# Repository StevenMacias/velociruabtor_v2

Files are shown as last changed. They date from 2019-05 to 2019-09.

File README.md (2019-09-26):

# VelocirUABtor v2

Competition line follower developed with the [UAB](https://www.uab.cat/web/universitat-autonoma-de-barcelona-1345467954774.html) Physical Computing Communitiy sponsorhip.

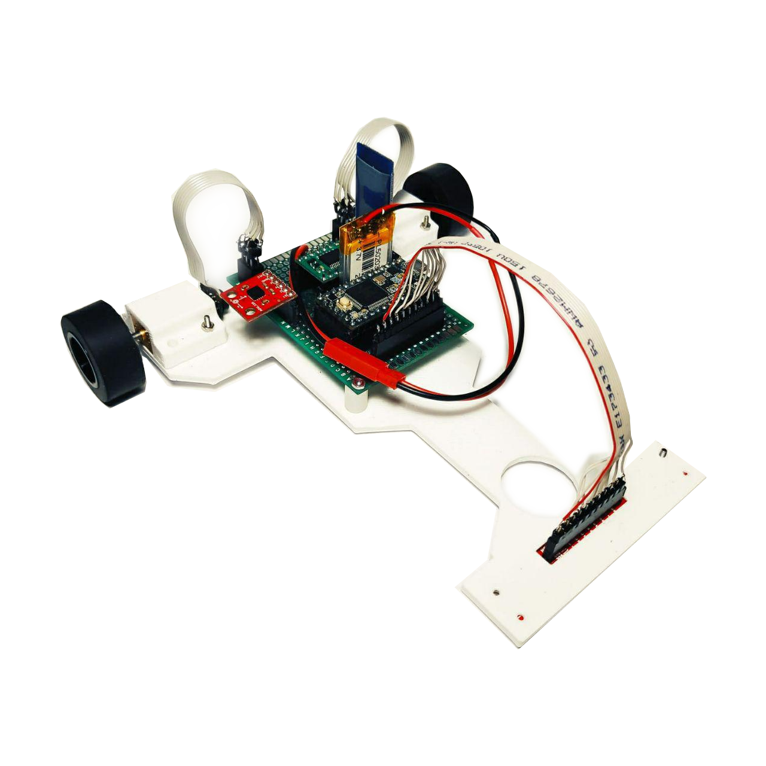
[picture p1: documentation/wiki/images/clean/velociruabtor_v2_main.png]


## Built With

In order to work in the project we recommend to use:
* [Atom](https://atom.io) - IDE.
* [PlatformIO](https://platformio.org/install/ide?install=atom) - Framework used to work with Teensy 3.2 that can be integrated in Atom.
* [GitKraken](https://www.gitkraken.com/) - Multiplatform Git client.
* [Procesing](https://processing.org/) - Language used to develop the user interface.
* [Fritzing](https://fritzing.org/home/) - Tool used to design the hardware connections.

## Main Components
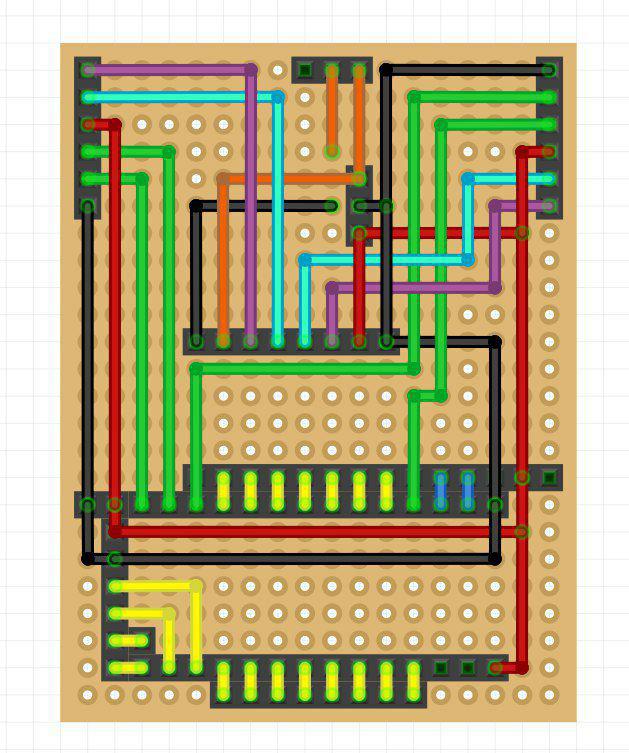
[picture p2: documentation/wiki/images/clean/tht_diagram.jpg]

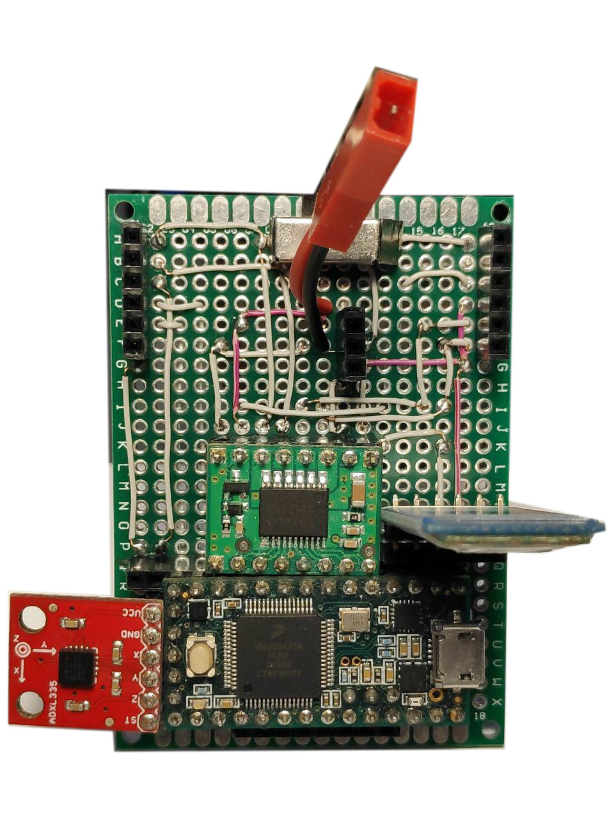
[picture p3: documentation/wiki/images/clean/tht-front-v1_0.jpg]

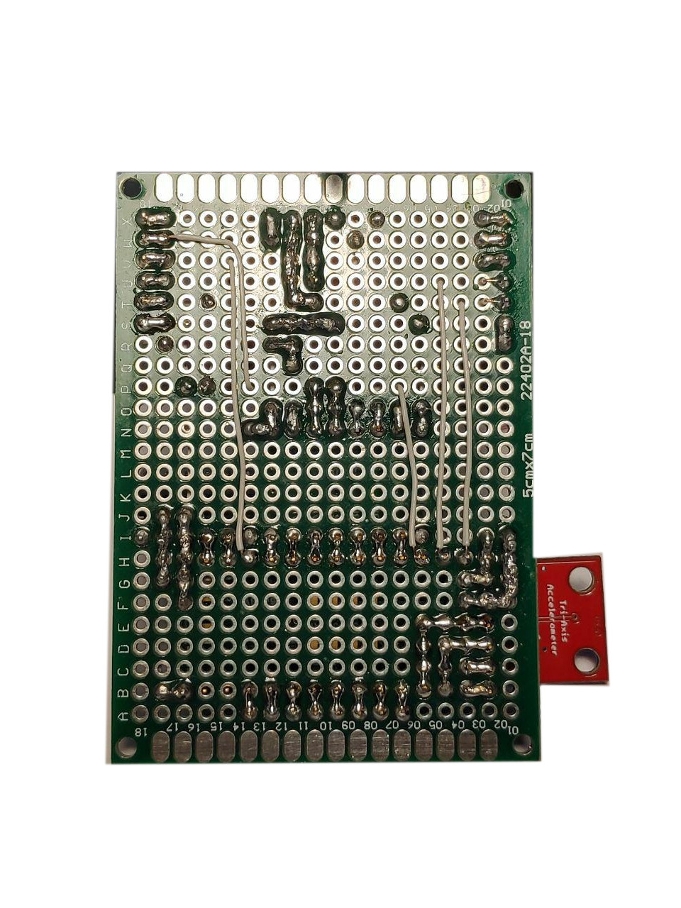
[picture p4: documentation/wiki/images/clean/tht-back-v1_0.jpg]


* [ADXL335](https://www.sparkfun.com/products/9269) - Accelerometer.
* [HC-05](https://components101.com/wireless/hc-05-bluetooth-module) - Bluetooth Module.
* [Pololu Magnetic Encoders](https://www.pololu.com/product/2598) - Encoders for micrometal motors.
* [TB6612FNG](https://www.pololu.com/product/713) - Motor Driver.
* [Reflectance Sensor Array](https://www.pololu.com/product/713) - Array of 8 IR sensors used to detect the track.
* [Teensy 3.2](https://www.pjrc.com/store/teensy32.html) -  32 bit ARM processor.

## User Interface
The microcontroller builds JSON frames with the sensors values that are transmitted to the laptop using the HC-05 module. 

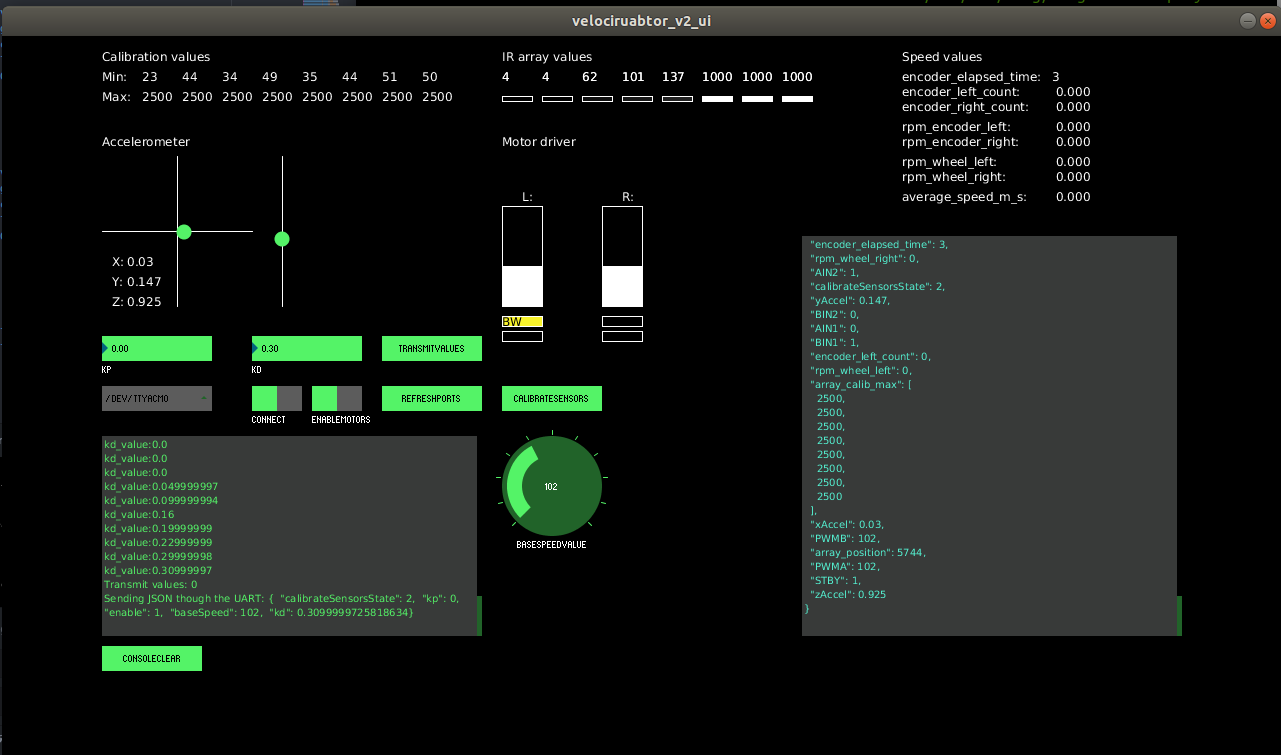
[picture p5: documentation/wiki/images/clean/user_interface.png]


## Authors

* **Steven Macías** - *Initial work* - [StevenMacias](https://github.com/StevenMacias)

## Contributors

* **Victor Escobedo** - *User interface features.* - [victorEscobedo](https://github.com/victorEscobedo)

## Acknowledgments

* **Fernando Vilariño** - *Mentor* - [Linkedin: fernandovilarino](https://www.linkedin.com/in/fernandovilarino/)

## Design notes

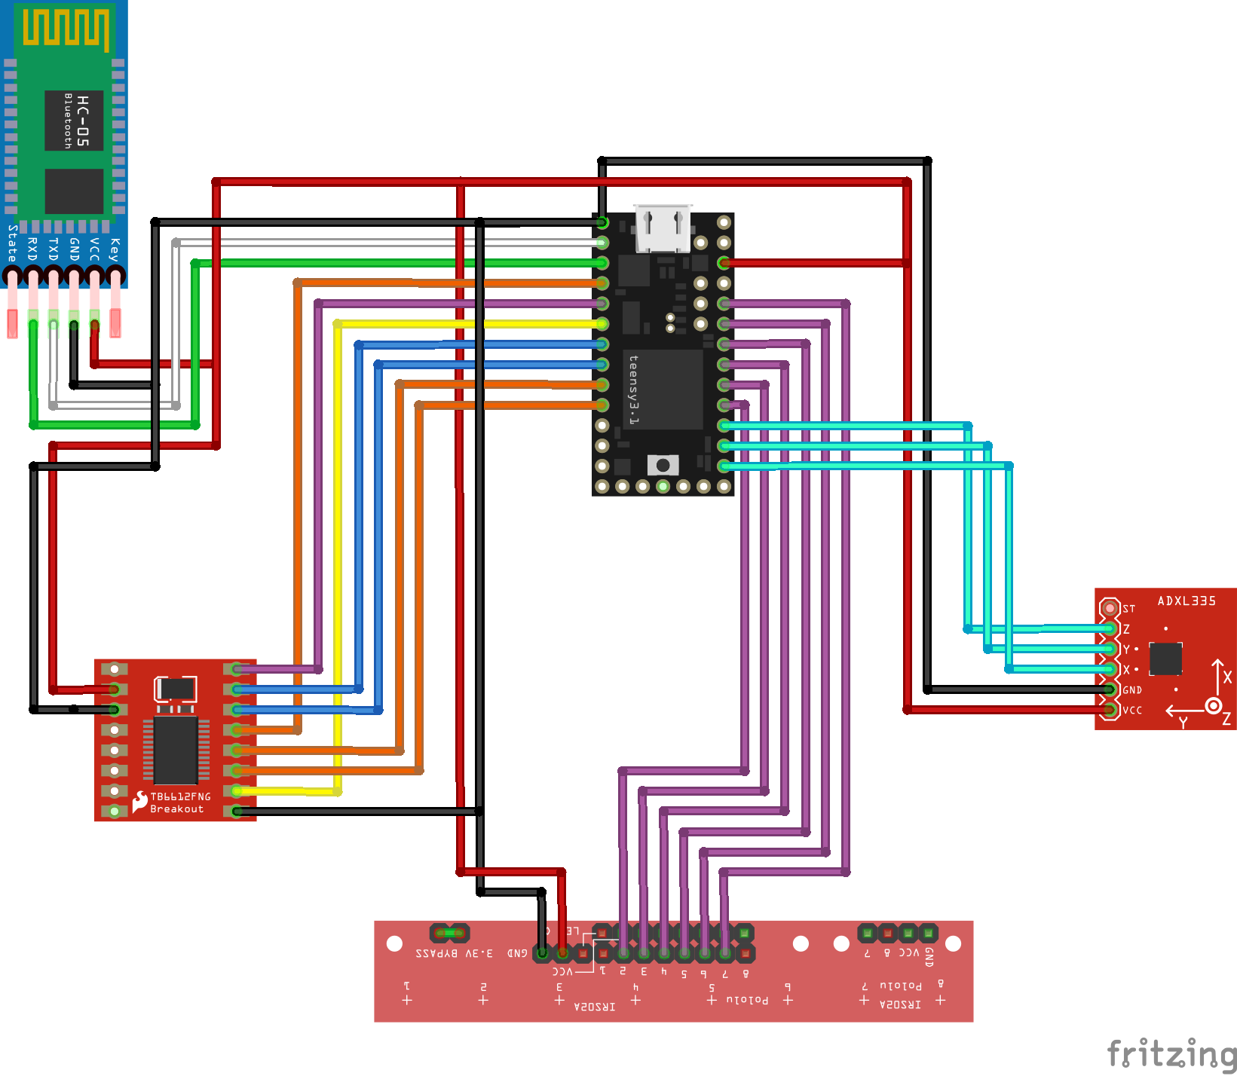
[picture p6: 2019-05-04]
documentation/System_Design/Fritzing/pictures/04_05_19/velociruabtor_v2_bb.png

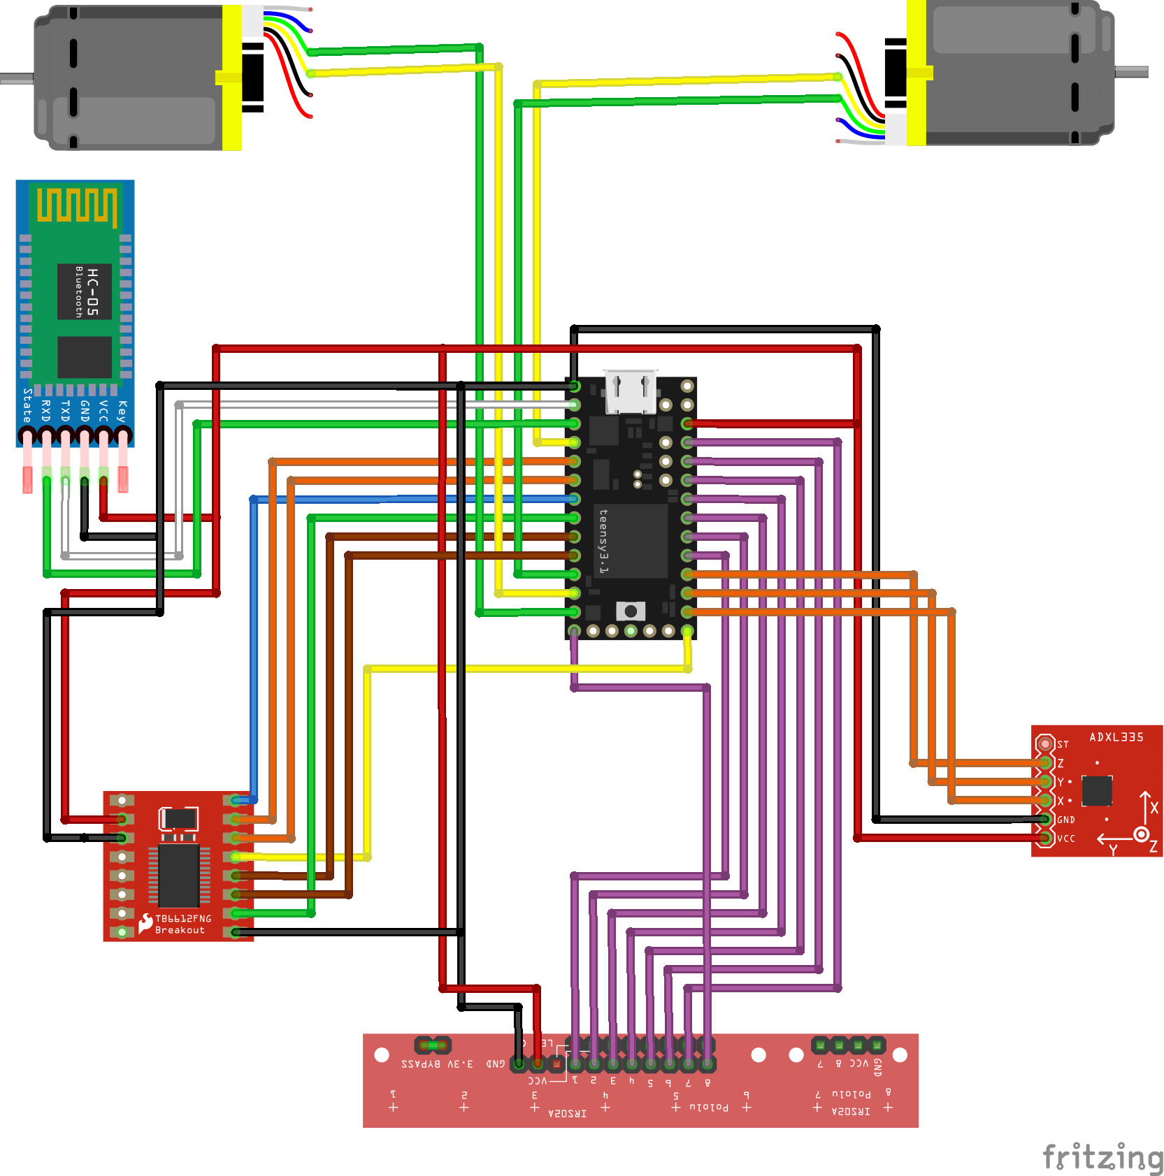
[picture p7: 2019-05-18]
documentation/System_Design/Fritzing/pictures/15_05_19/velociruabtor_v2_bb.png

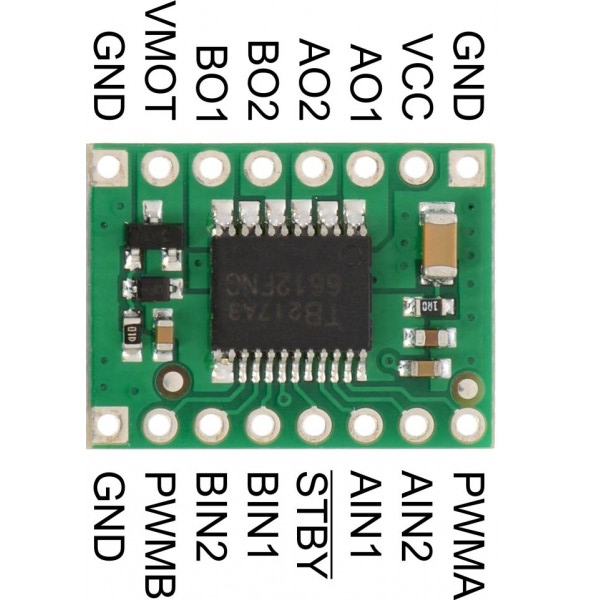
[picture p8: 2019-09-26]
documentation/System_Design/Hardware/Motor_Driver-TB6612FNG/tb6612fng_pinout.jpg

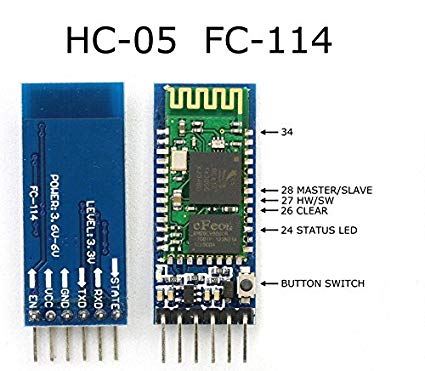
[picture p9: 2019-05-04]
documentation/System_Design/Hardware/Bluetooth-HC05/HC05-pinout.jpg

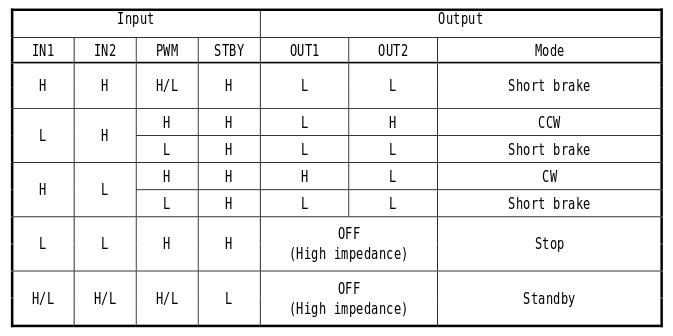
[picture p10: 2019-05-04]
documentation/System_Design/Hardware/Motor_Driver-TB6612FNG/motor_driver_table.png

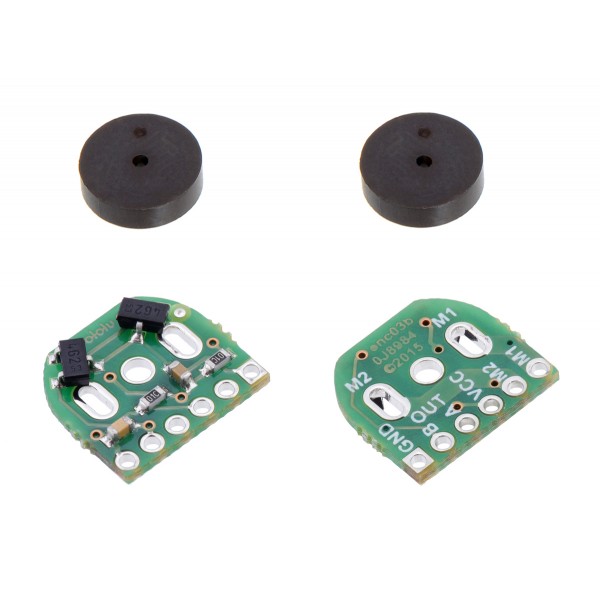
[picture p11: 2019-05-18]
documentation/System_Design/Hardware/Encoders/encoders-para-motores-micro-metal-12cpr.jpg

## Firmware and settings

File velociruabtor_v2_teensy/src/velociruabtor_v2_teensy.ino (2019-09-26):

/**
Velociruabtor V2
velociruabtor_v2_teensy.ino
Purpose: Develop a line follower using Teensy 3.2

@author Steven Macías and Victor Escobedo
@version 1.0 22/04/2019
*/
#include <Arduino.h>
#include <ArduinoJson.h>
#include <QTRSensors.h>
#include <Encoder.h>
#include "Accelerometer.h"
#include "Motor_driver.h"

#define PI 3.1415926535897932384626433832795
#define WHEEL_GEAR_DIVIDER 10.00
#define WHEEL_DIAMETER_MILIMETERS 28.00
#define WHEEL_PERIMETER (PI*WHEEL_DIAMETER_MILIMETERS)
#define ENCODER_OPTIMIZE_INTERRUPTS
#define BT_SERIAL Serial1
#define CABLE_SERIAL Serial
#define BT_UART_BAUDRATE 38400
#define CABLE_UART_BAUDRATE 115200
#define NUM_SENSORS 8
#define ARDUINOJSON_DEFAULT_NESTING_LIMIT 4

#define Kp 0.1 // experiment to determine this, start by something small that just makes your bot follow the line at a slow speed
#define Kd 4// experiment to determine this, slowly increase the speeds and adjust this value. ( Note: Kp < Kd)
#define MaxSpeed 255// max speed of the robot
#define BaseSpeed 255 // this is the speed at which the motors should spin when the robot is perfectly on the line
#define NUM_SENSORS  8     // number of sensors used
#define speedturn 180


QTRSensorsRC qtrrc((unsigned char[]) {A2, A3, A4, A5, A6, A7, A8, A9} ,NUM_SENSORS, 2500, QTR_NO_EMITTER_PIN);
StaticJsonDocument<1024> json;
StaticJsonDocument<2048> rx_json;
Accelerometer accel;
Motor_driver motor_driver;
int position = 0;
unsigned int sensorValues[NUM_SENSORS];
int motorValues[7];
int lastError = 0;
unsigned long start_time = millis();
unsigned long end_time = millis();
Encoder encoderLeft(2, 10);
Encoder encoderRight(12, 11); // Pins inversed
float rpm_encoder_left = 0;
float rpm_encoder_right = 0;
float rpm_wheel_left = 0;
float rpm_wheel_right = 0;
float average_speed_m_s = 0;
int calibrateSensorsState = 0;
int jsonError = 0;
unsigned long encoder_elapsed_time = 0;
long encoder_left_count, encoder_right_count;
char serial_data[2048] = "";
int enable = 0;
float kp = 1;
float kd = 1;
int baseSpeed = 0;
int maxSpeed = 255;
int period = 200;
unsigned long time_now = 0;
boolean lets_start = false;

const byte numChars = 512;
char receivedChars[numChars];   // an array to store the received data
boolean newData = false;


/**
Builds a JSON string that contains all the data regarging the line follower.
@param none
@return void
*/
void buildAccelJson()
{
  json.clear();
  // Acceleremoter values
  json["xAccel"] = accel.getX();
  json["yAccel"] = accel.getY();
  json["zAccel"] = accel.getZ();

  // Array Sensors values
  uint8_t i;
  for(i=0; i<NUM_SENSORS; i++)
  {
    json["array_calib_min"].add(qtrrc.calibratedMinimumOn[i]);
    json["array_calib_max"].add(qtrrc.calibratedMaximumOn[i]);
    position = qtrrc.readLine(sensorValues);
    json["array_values"].add(sensorValues[i]);
  }
  json["array_position"] = position;
}

/**
Builds a JSON string that contains all the data regarging the motor driver.
@param none
@return void
*/
void buildMotorDriverJson()
{
  json["PWMA"] = motorValues[0];
  json["AIN1"] = motorValues[2];
  json["AIN2"] = motorValues[1];
  json["PWMB"] = motorValues[3];
  json["BIN1"] = motorValues[4];
  json["BIN2"] = motorValues[5];
  json["STBY"] = motorValues[6];
}

void buildEncoderJson()
{
  json["rpm_encoder_left"] = rpm_encoder_left;
  json["rpm_encoder_right"] = rpm_encoder_right;
  json["encoder_elapsed_time"] = encoder_elapsed_time;
  json["rpm_wheel_left"] = rpm_wheel_left;
  json["rpm_wheel_right"] = rpm_wheel_right;
  json["average_speed_m_s"] = average_speed_m_s;
  json["encoder_left_count"] = encoder_left_count;
  json["encoder_right_count"] = encoder_right_count;
  json["calibrateSensorsState"] = calibrateSensorsState;
  json["jsonError"] = jsonError;
  json["lets_start"] = lets_start;
}


/**
Calibrates the QTR-RC Sensor array
@param none
@return void
*/
void calibrateQtrc()
{
  int i = 0;
  for (int i; i < 20; i++) // calibrate for sometime by sliding the sensors across the line, or you may use auto-calibration instead
  { 	//Added open brace here

    // GO TO RIGHT
    if ( i  <= 5 || i >= 15 ) // turn to the left and right to expose the sensors to the brightest and darkest readings that may be encountered
    {
      motor_driver.runMotorDriver(85, LOW, HIGH, 85, LOW, HIGH, HIGH);
    }
    // GOT TO LEFT
    else
    {
      motor_driver.runMotorDriver(85, HIGH, LOW, 85, HIGH, LOW, HIGH);
    }
    qtrrc.calibrate();
    delay(20);

  }  	//Added close brace here
  calibrateSensorsState = 2;
  motor_driver.runMotorDriver(0, LOW, HIGH, 0, HIGH, LOW, LOW);

}

/**
Function that initializes the system
@param none
@return void
*/
void setup()
{
  pinMode(LED_BUILTIN, OUTPUT);
  pinMode(A1, INPUT);
  pinMode(A0, INPUT);
  pinMode(A14, INPUT);
  //digitalWrite(LED_BUILTIN, HIGH);
  json.clear();
  // Configure Bluetooth UART
  BT_SERIAL.begin(BT_UART_BAUDRATE);
  // Configure USB UART
  CABLE_SERIAL.begin(CABLE_UART_BAUDRATE);
  // Create Objects
  accel = Accelerometer();
  motor_driver = Motor_driver();
  //motor_driver.enableMotors();
  // Calibrate Sensors Array
  calibrateQtrc();
  //digitalWrite(LED_BUILTIN, LOW);
  BT_SERIAL.setTimeout(200);
}

/**
Test function for the motor driver
@param none
@return void
*/
void testMotorDriver()
{
  static int i=0;
  static bool forward = true;

  if(forward == true)
  {
    motor_driver.runMotorDriver(i, LOW, HIGH, i, LOW, HIGH, HIGH);
  }else{
    motor_driver.runMotorDriver(i, HIGH, LOW, i, HIGH, LOW, HIGH);
  }
  i++;
  if(i>=255)
  {
    forward = !forward;
    i = 0;
  }
}

void computePidAndDrive()
{
  position = qtrrc.readLine(sensorValues); // get calibrated readings along with the line position, refer to the QTR Sensors Arduino Library for more details on line position.

  if(position>6700){
    //motor_driver.runMotorDriver(speedturn, HIGH, LOW, speedturn, LOW, HIGH, enable);
    motor_driver.runMotorDriver(baseSpeed, HIGH, LOW, baseSpeed, HIGH, LOW, enable);
    return;
  }
  if(position<300){
    //motor_driver.runMotorDriver(speedturn, LOW, HIGH, speedturn, HIGH, LOW, enable);
    motor_driver.runMotorDriver(baseSpeed, LOW, HIGH, baseSpeed, LOW, HIGH, enable);

    return;
  }

  int error = position - 3500;
  int motorSpeed = kp * error + kd * (error - lastError);
  lastError = error;

  int rightMotorSpeed = baseSpeed + motorSpeed;
  int leftMotorSpeed = baseSpeed - motorSpeed;

  if((baseSpeed+(baseSpeed*0.5)) > 255)
  {
    maxSpeed = 255u;
  }else
  {
    maxSpeed = baseSpeed+(baseSpeed*0.25);
  }
  if (rightMotorSpeed > (maxSpeed) ) rightMotorSpeed = maxSpeed; // prevent the motor from going beyond max speed
  if (leftMotorSpeed > maxSpeed ) leftMotorSpeed = maxSpeed; // prevent the motor from going beyond max speed
  if (rightMotorSpeed < 0)rightMotorSpeed = 0;
  if (leftMotorSpeed < 0)leftMotorSpeed = 0;
  motor_driver.runMotorDriver(leftMotorSpeed, LOW, HIGH,rightMotorSpeed , HIGH, LOW, enable);
}

void calculateRPM()
{
  end_time = millis();
  encoder_elapsed_time = end_time - start_time;

  encoder_left_count = encoderLeft.read();
  encoder_right_count = encoderRight.read();
  //rpm_encoder_left = 60000.00*encoder_left_count/encoder_elapsed_time/12;
  //rpm_encoder_right = 60000.00*encoder_right_count/encoder_elapsed_time/12;
  rpm_encoder_left = ((encoder_left_count/12.00)/encoder_elapsed_time)*60000;
  rpm_encoder_right = ((encoder_right_count/12.00)/encoder_elapsed_time)*60000;
  rpm_wheel_left = rpm_encoder_left/WHEEL_GEAR_DIVIDER;
  rpm_wheel_right = rpm_encoder_right/WHEEL_GEAR_DIVIDER;

  average_speed_m_s = (((rpm_wheel_left+rpm_wheel_right)/2)*WHEEL_PERIMETER/1000)/60; //Average wheel speed * perimeter / 60 seconds = meters/second
  encoderLeft.write(0);
  encoderRight.write(0);
  start_time = millis();
}

void sendJsonByBluetooth(boolean force)
{
    // avoid uart saturation
    if(((millis() > time_now + period) || force)&&lets_start){
      motor_driver.getMotorDriverValues(motorValues);
      accel.getData();
      buildAccelJson();
      buildMotorDriverJson();
      buildEncoderJson();
      time_now = millis();
      serializeJson(json, BT_SERIAL);
      serializeJson(json, CABLE_SERIAL);
      BT_SERIAL.print('\n');
      CABLE_SERIAL.print('\n');
  }
}
/**
Main loop of the project
@param none
@return void
*/
void loop()
{
  calculateRPM();
  computePidAndDrive();
  sendJsonByBluetooth(false);



  /*if(CABLE_SERIAL.available() > 0) {
    //a= Serial.readString();// read the incoming data as string
    CABLE_SERIAL.readBytesUntil('\n', serial_data, 128);
    rx_json.clear();
    deserializeJson(rx_json, serial_data);
    enable = rx_json["enable"];
    kp = rx_json["kp"];
    kd = rx_json["kd"];
    baseSpeed = rx_json["baseSpeed"];
    calibrateSensorsState = rx_json["calibrateSensorsState"];
  }*/
  /*if(BT_SERIAL.available()) {
    //a= Serial.readString();// read the incoming data as string
    if(BT_SERIAL.readBytesUntil('\n', serial_data, sizeof(serial_data)-1) > 0){
      rx_json.clear();
      DeserializationError err = deserializeJson(rx_json, serial_data,DeserializationOption::NestingLimit(4));

      switch (err.code()) {
      case DeserializationError::Ok:
          enable = rx_json["enable"];
          kp = rx_json["kp"];
          kd = rx_json["kd"];
          baseSpeed = rx_json["baseSpeed"];
          calibrateSensorsState = rx_json["calibrateSensorsState"];
          lets_start = rx_json["lets_start"];
          jsonError = 0;
          break;
      case DeserializationError::InvalidInput:
          jsonError = 1;
          digitalWrite(LED_BUILTIN,HIGH);
          delay(50);
          BT_SERIAL.flush();
          digitalWrite(LED_BUILTIN,LOW);
          break;
      case DeserializationError::NoMemory:
          jsonError = 2;
          break;
      default:
          jsonError = 3;
          break;
        }

      sendJsonByBluetooth(true);
      while (Serial.available() > 0) {
        BT_SERIAL.read();
      }

    }
  }*/

  if((calibrateSensorsState == 1)&&(lets_start ==1))
  {
    sendJsonByBluetooth(true);
    calibrateQtrc();
  }
  //delay(22);

  recvWithEndMarker();
    showNewData();
}

void recvWithEndMarker() {
    static byte ndx = 0;
    char endMarker = '\n';
    char rc;

    while (BT_SERIAL.available() > 0 && newData == false) {
        rc = BT_SERIAL.read();

        if (rc != endMarker) {
            receivedChars[ndx] = rc;
            ndx++;
            if (ndx >= numChars) {
                ndx = numChars - 1;
            }
        }
        else {
            receivedChars[ndx] = '\n'; // terminate the string
            receivedChars[ndx+1] = '\0'; // terminate the string
            BT_SERIAL.print(ndx );
            BT_SERIAL.print('\n');
            ndx = 0;
            newData = true;
        }
    }
}

void showNewData() {
    if (newData == true) {
      rx_json.clear();
      DeserializationError err = deserializeJson(rx_json, receivedChars,DeserializationOption::NestingLimit(4));

      switch (err.code()) {
      case DeserializationError::Ok:
          enable = rx_json["enable"];
          kp = rx_json["kp"];
          kd = rx_json["kd"];
          baseSpeed = rx_json["baseSpeed"];
          calibrateSensorsState = rx_json["calibrateSensorsState"];
          lets_start = rx_json["lets_start"];
          jsonError = 0;
          break;
      case DeserializationError::InvalidInput:
          jsonError = 1;
          digitalWrite(LED_BUILTIN,HIGH);
          delay(50);
          BT_SERIAL.flush();
          digitalWrite(LED_BUILTIN,LOW);
          break;
      case DeserializationError::NoMemory:
          jsonError = 2;
          break;
      default:
          jsonError = 3;
          break;
        }

      sendJsonByBluetooth(true);
        newData = false;
    }
}

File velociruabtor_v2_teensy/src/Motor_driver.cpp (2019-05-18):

/*
  Morse.cpp - Library for flashing Morse code.
  Created by David A. Mellis, November 2, 2007.
  Released into the public domain.
*/

#include "Arduino.h"
#include "Motor_driver.h"

Motor_driver::Motor_driver()
{
   pinMode(pinAIN2, OUTPUT);
   pinMode(pinAIN1, OUTPUT);
   pinMode(pinPWMA, OUTPUT);
   pinMode(pinBIN1, OUTPUT);
   pinMode(pinBIN2, OUTPUT);
   pinMode(pinPWMB, OUTPUT);
   pinMode(pinSTBY, OUTPUT);
}
void Motor_driver::move(int direction, int speed)
{
   if (direction == forward)
   {
      moveMotorForward(pinMotorA, speed);
      moveMotorForward(pinMotorB, speed);
   }
   else
   {
      moveMotorBackward(pinMotorA, speed);
      moveMotorBackward(pinMotorB, speed);
   }
}

void Motor_driver::turn(int direction, int speed)
{
   if (direction == forward)
   {
      moveMotorForward(pinMotorA, speed);
      moveMotorBackward(pinMotorB, speed);
   }
   else
   {
      moveMotorBackward(pinMotorA, speed);
      moveMotorForward(pinMotorB, speed);
   }
}

void Motor_driver::fullStop()
{
   disableMotors();
   stopMotor(pinMotorA);
   stopMotor(pinMotorB);
}

//Funciones que controlan los motores
void Motor_driver::moveMotorForward(const int pinMotor[3], int speed)
{
   digitalWrite(pinMotor[1], HIGH);
   digitalWrite(pinMotor[2], LOW);

   analogWrite(pinMotor[0], speed);
}

void Motor_driver::moveMotorBackward(const int pinMotor[3], int speed)
{
   digitalWrite(pinMotor[1], LOW);
   digitalWrite(pinMotor[2], HIGH);

   analogWrite(pinMotor[0], speed);
}

void Motor_driver::stopMotor(const int pinMotor[3])
{
   digitalWrite(pinMotor[1], LOW);
   digitalWrite(pinMotor[2], LOW);

   analogWrite(pinMotor[0], 0);
}

void Motor_driver::enableMotors()
{
   digitalWrite(pinSTBY, HIGH);
}

void Motor_driver::disableMotors()
{
   digitalWrite(pinSTBY, LOW);
}

void Motor_driver::test()
{
  enableMotors();
  move(forward, 180);
  delay(waitTime);

  move(backward, 180);
  delay(waitTime);

  turn(clockwise, 180);
  delay(waitTime);

  turn(counterClockwise, 180);
  delay(waitTime);

  fullStop();
  delay(waitTime);
}

void Motor_driver::runMotorDriver(int pwmaVal, int aIn1Val, int aIn2Val, int pwmbVal, int bIn1Val, int bIn2Val, int stbyVal)
{
  // STBY PIN
  digitalWrite(pinSTBY, stbyVal);
  _stbyVal = stbyVal;
  // MOTOR A
  analogWrite(pinMotorA[0], pwmaVal);
  _pwmaVal = pwmaVal;
  digitalWrite(pinMotorA[1], aIn2Val);
  _aIn2Val = aIn2Val;
  digitalWrite(pinMotorA[2], aIn1Val);
  _aIn1Val = aIn1Val;
  // MOTOR B
  analogWrite(pinMotorB[0], pwmbVal);
  _pwmbVal = pwmbVal;
  digitalWrite(pinMotorB[1], bIn1Val);
  _bIn1Val = bIn1Val;
  digitalWrite(pinMotorB[2], bIn2Val);
  _bIn2Val = bIn2Val;
}

void Motor_driver::test2()
{
  int i;
  for(i=0; i<255; i++)
  {
    runMotorDriver(i, HIGH, LOW, i, HIGH, LOW, HIGH);
    delay(5);
  }
  for(i=0; i<255; i++)
  {
    runMotorDriver(i, LOW, HIGH, i, LOW, HIGH, HIGH);
    delay(5);
  }
}

void Motor_driver::getMotorDriverValues(int *values)
{
  values[0] = _pwmaVal;
  values[1] = _aIn2Val;
  values[2] = _aIn1Val;
  values[3] = _pwmbVal;
  values[4] = _bIn1Val;
  values[5] = _bIn2Val;
  values[6] = _stbyVal;
}

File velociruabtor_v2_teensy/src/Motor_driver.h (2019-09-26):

// Pinout
const int pinPWMA = 3;
const int pinAIN2 = 4;
const int pinAIN1 = 5;
const int pinBIN1 = 7;
const int pinBIN2 = 8;
const int pinPWMB = 9;
const int pinSTBY = 6;

const int waitTime = 2000;   //espera entre fases
const int speed = 200;      //velocidad de giro

const int pinMotorA[3] = { pinPWMA, pinAIN2, pinAIN1 };
const int pinMotorB[3] = { pinPWMB, pinBIN1, pinBIN2 };

enum moveDirection {
   forward,
   backward
};

enum turnDirection {
   clockwise,
   counterClockwise
};

class Motor_driver
{
  public:
    Motor_driver();
    void move(int direction, int speed);
    void turn(int direction, int speed);
    void fullStop();
    void moveMotorForward(const int pinMotor[3], int speed);
    void moveMotorBackward(const int pinMotor[3], int speed);
    void stopMotor(const int pinMotor[3]);
    void enableMotors();
    void disableMotors();
    void test();
    void test2();
    void runMotorDriver(int pwmaVal, int aIn1Val, int aIn2Val, int pwmbVal, int bIn1Val, int bIn2Val, int stbyVal);
    void getMotorDriverValues(int *values);
  private:
    int _pwmaVal=0;
    int _aIn1Val=0;
    int _aIn2Val=0;
    int _pwmbVal=0;
    int _bIn1Val=0;
    int _bIn2Val=0;
    int _stbyVal=0;
};

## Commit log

2019-04-27 First commit
    The project has the bluetooth, accelerometer and the array of sensors configured. In the user interface you are alowed to see the main data of it's components.
2019-04-28 Migration from Arduino IDE to Platformio
    Created a project in Atom using Platformio to make the development easier.
2019-04-28 Solved bug in accelerometer
    Z axis was wrong.
    [velociruabtor_v2_teensy.ino]
2019-04-28 prueba básica para el Motor L | añadido primera versión del botón
2019-05-01 Solved bug in accelerometer values
    Solved a bug in the accelerometer values and changed the port to the one used in Ubuntu.
    [velociruabtor_v2_ui.pde]
2019-05-03 Added documentation folder
    This folder includes the fritzing diagram and hardware pinout.
    [velociruabtor_v2.fzz]
2019-05-04 Motor Driver Graph v1.0
2019-05-04 Added pinout images and created the files related to the motor driver
    [velociruabtor_v2.fzz]
2019-05-04 Motor driver integrated
2019-05-05 First approach for the PID function
2019-05-10 Updated number of array sensor from 6 to 8
2019-05-14 Motor Driver UI v2.0
2019-05-14 Updated fritzing and applied new pinout
    [velociruabtor_v2.fzz]
2019-05-15 Solved bug with standby and updated fritzing
    [velociruabtor_v2.fzz]
2019-05-17 Added debug print function
2019-05-17 Added .gitattributes to avoid end of line conflicts with Windows
    [velociruabtor_v2_ui.pde]
2019-05-18 Added encoder functions, json and basic UI.
    There is a bug with the negatives values for the encoders.
    [velociruabtor_v2_teensy.ino, velociruabtor_v2_ui.pde]
2019-05-19 Bugfix in rpm calculation, print econders values in the user interface.
    [velociruabtor_v2_teensy.ino, velociruabtor_v2_ui.pde]
2019-05-22 Added buttons to select the serial port.
2019-06-02 Deleted the old port selector and added toggles for connection and motor
2019-06-02 Implemented motor enable from the UI to the device via bluetooth.
2019-06-21 Uploaded issue video and THT fritzing
    [velociruabtor_v2_tht.fzz]
2019-06-24 Lots of changes after rebuilding the PCB.
2019-07-19 Calibrated accelerometer, added calibrate button and direction bugfix.
    [velociruabtor_v2_teensy.ino, velociruabtor_v2_ui.java, velociruabtor_v2_ui.pde]
2019-09-04 Solved some motor direction bug
    [velociruabtor_v2_teensy.ino, velociruabtor_v2_ui.java, velociruabtor_v2_ui.pde]
